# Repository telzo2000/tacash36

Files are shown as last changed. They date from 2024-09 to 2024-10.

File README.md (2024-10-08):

# tacash36

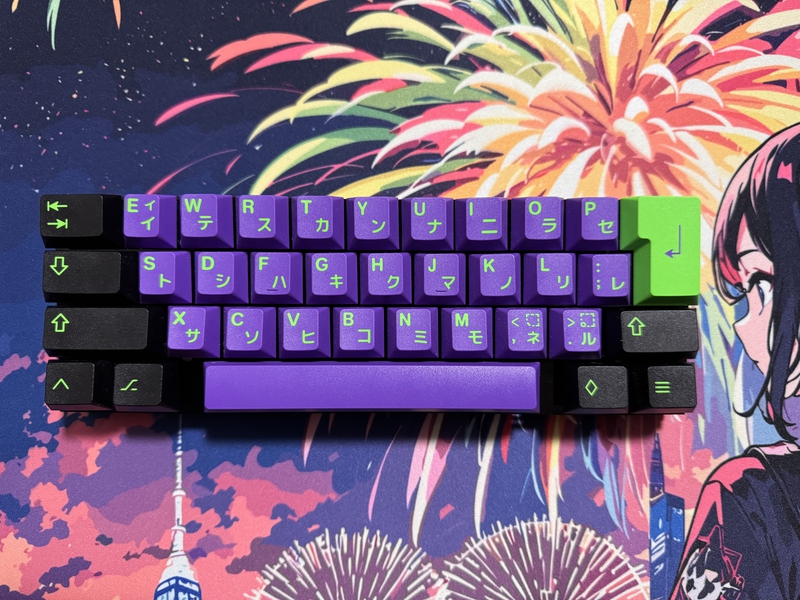
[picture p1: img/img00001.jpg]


## What is tacash36?

tacash36 is small keyboard.
<br>
tacash36 has 36keys.
<br>

This layout has this image.
<br>

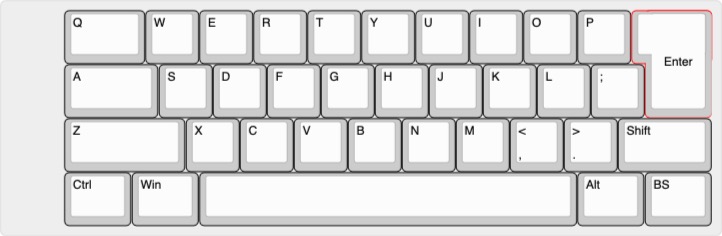
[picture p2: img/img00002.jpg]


This keyboard use Pro micro or BLE Micro Pro, run qmk_firmware.
<br>
With this keyboard, you can edit your favorite keymap using vial.

<br>

## firmware

https://github.com/telzo2000/tacash36/tree/main/firmware

## Build guide

https://github.com/telzo2000/tacash36/blob/main/buildguide_for_tacash36.md

## Parts list

| No. | Patrs | Quantity | remarks | Suppliers | Cost |
|--|--|--|--|--|--|
|番号|名前|数|備考|調達先|参考価格（送料込）|<br>
|1|PCB|1|36key|[elecrow](https://www.elecrow.com)<br>[JLCPCB](https://jlcpcb.com)<br>[ALLPCB](https://www.allpcb.com)|５枚で20〜30ドル|<br>
|2|BLE Micro Pro|1|MCU Board|[遊舎工房](https://shop.yushakobo.jp/products/ble-micro-pro?variant=37665571340449)|4950円|
|3|Swith socket<br>スイッチソケット|36|cherry MX互換|[遊舎工房](https://yushakobo.jp)<br>[Talp Keyboard](https://talpkeyboard.net)<br>[Daily Craft Keyboard](https://shop.dailycraft.jp)等|10個で165円程度|
|4|Diode<br>ダイオード|36|リードタイプでもSMDでも可|[遊舎工房](https://yushakobo.jp)<br>[Talp Keyboard](https://talpkeyboard.net)<br>[Daily Craft Keyboard](https://shop.dailycraft.jp)等|100個で220円程度から|
|5a|Switch plate|1|FR-4|[elecrow](https://www.elecrow.com)<br>[JLCPCB](https://jlcpcb.com)<br>[ALLPCB](https://www.allpcb.com)|５枚で20〜30ドル|
|5b|Switch plate|1|3D Print|||
|5c|Switch plate|1|Acrylic|[elecrow](https://www.elecrow.com/acrylic-cutting.html)|5枚で９ドル程度（送料込み）|
|6|Bottom case|1|3D Print||
|7|Screw<br>ネジ|8|M2 6mm|DIY shop|10本200円程度|
|8|Spacer<br>スペーサー|4|M2 6mm|DIY shop|10本400円程度|
|9|Stabilizer<br>スタビライザー|3|2Ux2,7Ux1|[遊舎工房](https://yushakobo.jp)<br>[Talp Keyboard](https://talpkeyboard.net)|セットで2000円程度|
|10|Conthrou<br>コンスルー|2|3.5mm|[遊舎工房](https://yushakobo.jp)<br>[Talp Keyboard](https://talpkeyboard.net)|１個400円程度|
|11|Keyswitch<br>キースイッチ|36|お好みで|[遊舎工房](https://yushakobo.jp)<br>[Talp Keyboard](https://talpkeyboard.net)<br>[Daily Craft Keyboard](https://shop.dailycraft.jp)|１個100程度|
|12|Keycap<br>キーキャップ|36|1Ux25、1.25Ux4、1.5Ux1、1.75Ux2、2.25Ux1、7Ux1|[遊舎工房](https://yushakobo.jp)<br>[Talp Keyboard](https://talpkeyboard.net)<br>[Daily Craft Keyboard](https://shop.dailycraft.jp)||
|13|ボタン電池ホルダー|1|1632|[アリエク](https://ja.aliexpress.com/item/32744211091.html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)<br>|100個で900円ほど|
|14|水平スライドスイッチ|1||[遊舎工房](https://shop.yushakobo.jp/products/5624?_pos=1&_sid=f65b70e3c&_ss=r)|110円|
|15|チップ積層セラミックコンデンサー |1|100μF6.3V F 3216|[秋月電子](https://akizukidenshi.com/catalog/g/g102151/)|10個入り200円|

※13,14,15は[遊舎工房のこれ](https://shop.yushakobo.jp/products/5623)が最適。

<br>
In addition, you will need a USB cable, etc.
<br>
この他に、USBケーブル等が必要です。
<br>

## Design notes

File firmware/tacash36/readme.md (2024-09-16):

# tacash36

tacash36

*A short description of the keyboard/project*

* Keyboard Maintainer: [m.ki](https://github.com/telzo2000)
* Hardware Supported: *The PCBs, controllers supported*
* Hardware Availability: *Links to where you can find this hardware*

Make example for this keyboard (after setting up your build environment):

    make tacash36:default

Flashing example for this keyboard:

    make tacash36:default:flash

See the [build environment setup](https://docs.qmk.fm/#/getting_started_build_tools) and the [make instructions](https://docs.qmk.fm/#/getting_started_make_guide) for more information. Brand new to QMK? Start with our [Complete Newbs Guide](https://docs.qmk.fm/#/newbs).

## Bootloader

Enter the bootloader in 3 ways:

* **Bootmagic reset**: Hold down the key at (0,0) in the matrix (usually the top left key or Escape) and plug in the keyboard
* **Physical reset button**: Briefly press the button on the back of the PCB - some may have pads you must short instead
* **Keycode in layout**: Press the key mapped to `QK_BOOT` if it is available

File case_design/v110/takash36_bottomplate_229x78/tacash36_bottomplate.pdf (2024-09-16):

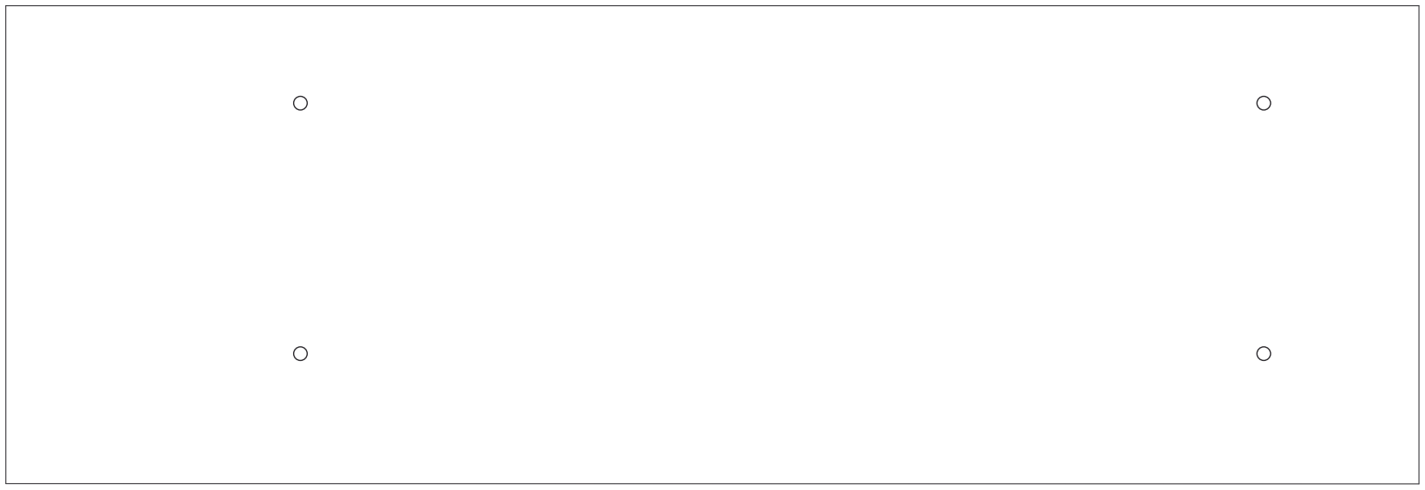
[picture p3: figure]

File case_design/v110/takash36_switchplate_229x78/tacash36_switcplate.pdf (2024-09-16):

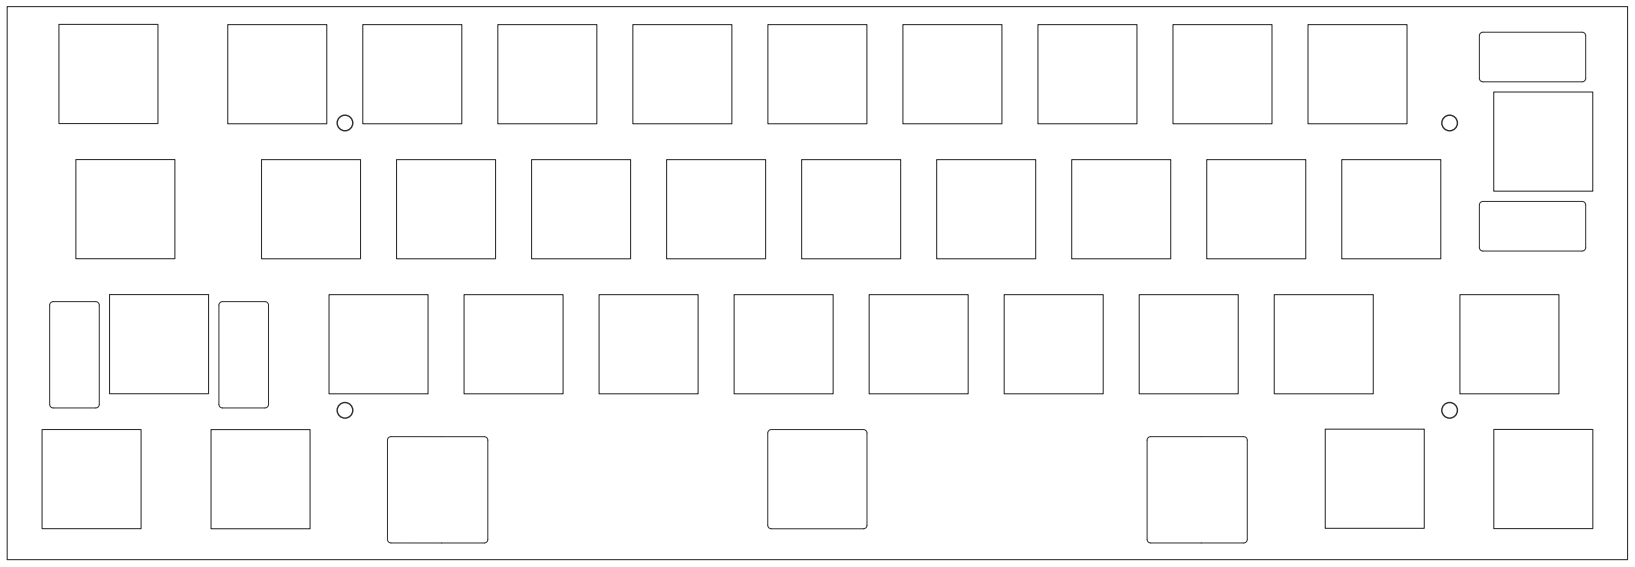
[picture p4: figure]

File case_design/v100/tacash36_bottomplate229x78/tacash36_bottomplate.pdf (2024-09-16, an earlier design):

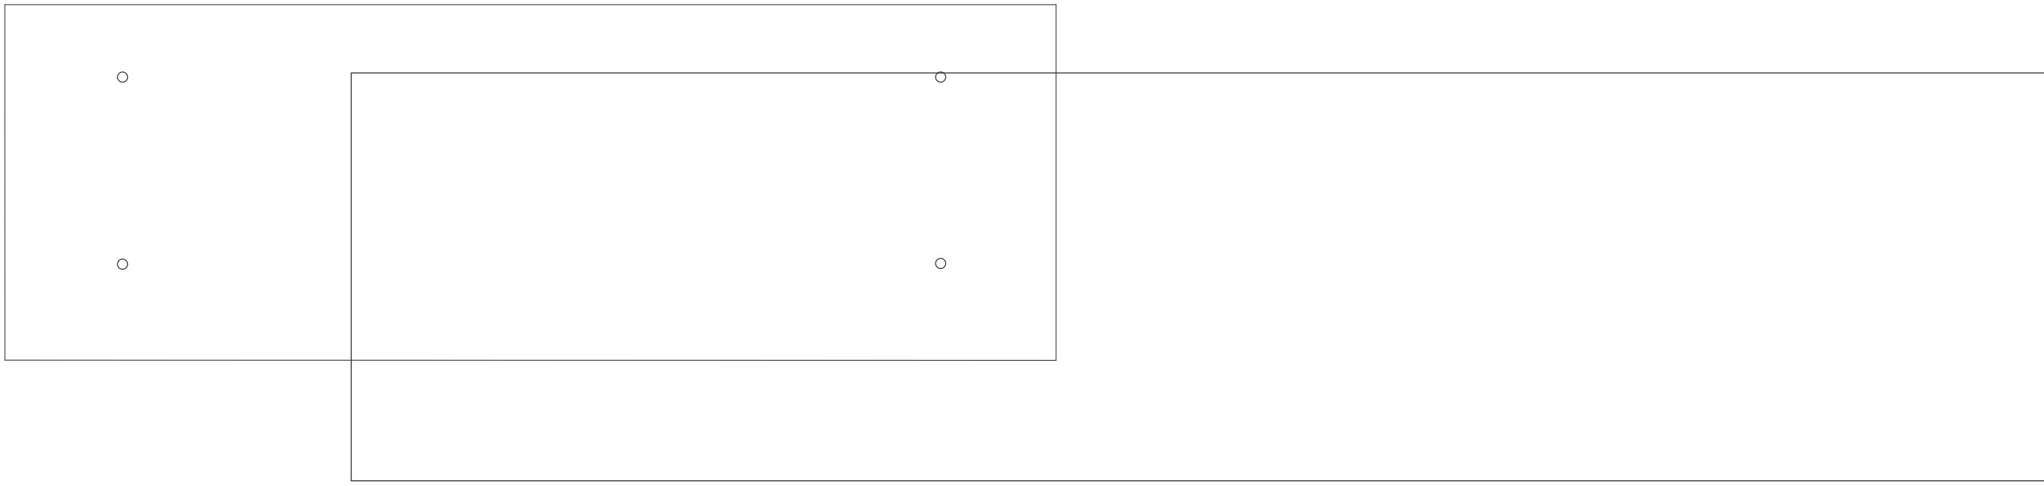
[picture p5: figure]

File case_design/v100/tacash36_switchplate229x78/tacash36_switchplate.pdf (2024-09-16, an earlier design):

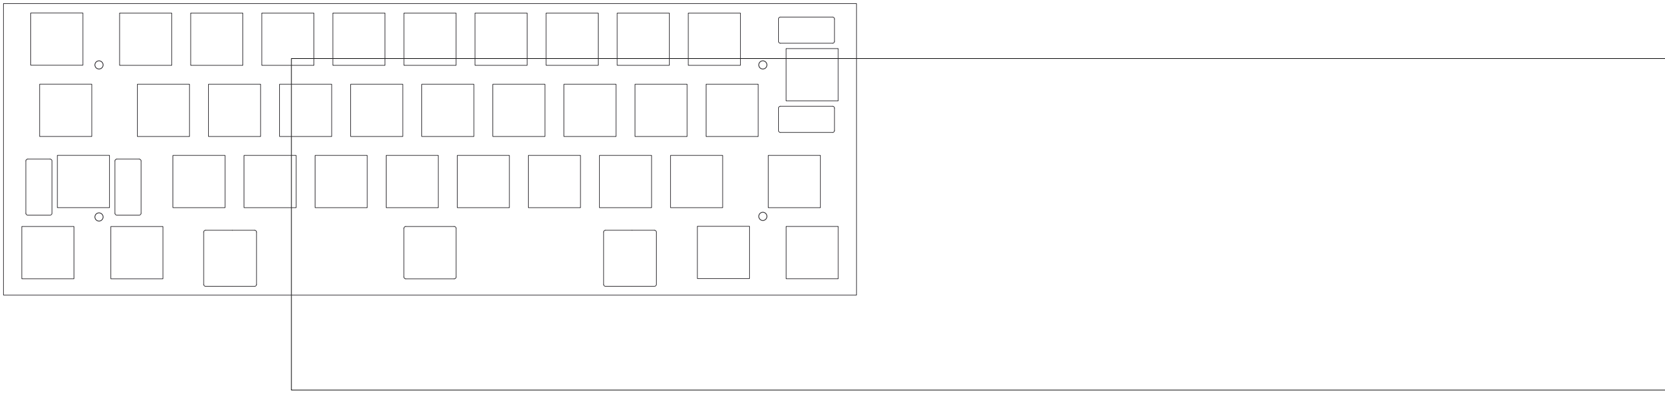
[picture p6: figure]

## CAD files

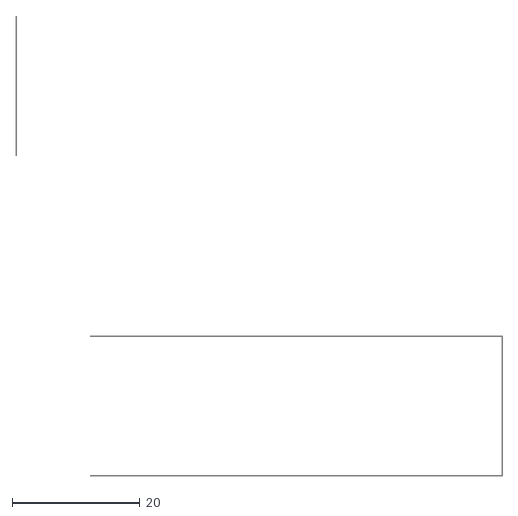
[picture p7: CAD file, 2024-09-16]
case_design/v110/takash36_bottomplate_229x78/tacash36_bottomplate.dxf
76.1 x 72.0

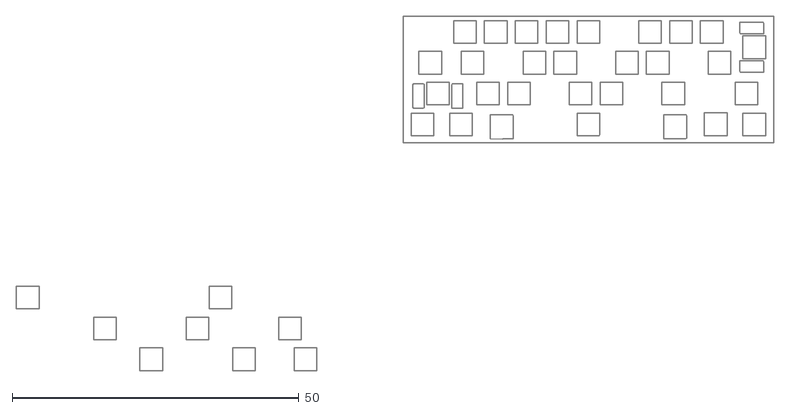
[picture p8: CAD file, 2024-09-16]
case_design/v110/takash36_switchplate_229x78/tacash36_switcplate.dxf
131.9 x 61.7

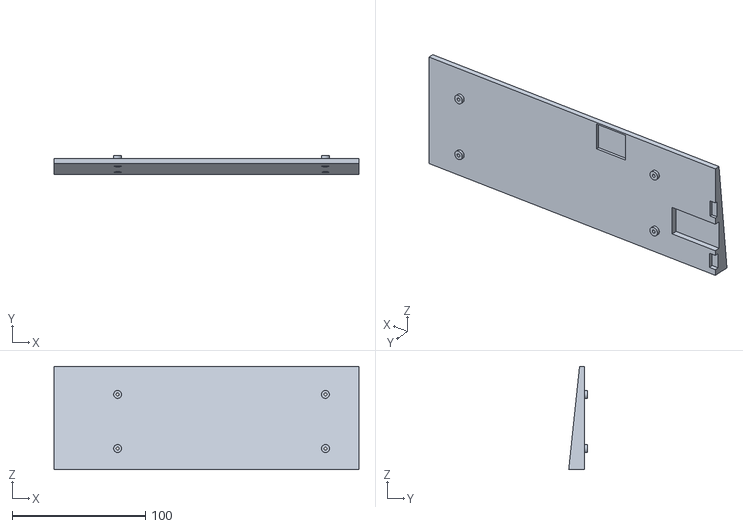
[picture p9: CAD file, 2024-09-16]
case_design/v110_bottomplate_3dprint/tacash36_bottomplate v2.stl
228.6 x 14.0 x 77.5

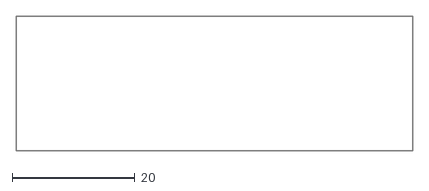
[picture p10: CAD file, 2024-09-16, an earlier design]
case_design/v100/tacash36_bottomplate229x78/tacash36_bottomplate.dxf
64.5 x 21.8

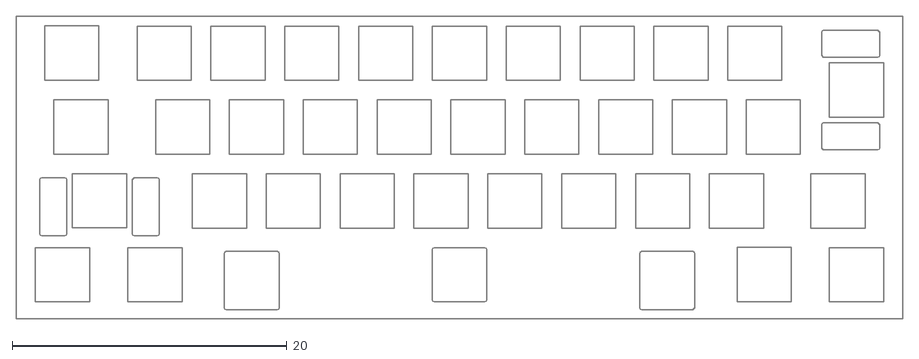
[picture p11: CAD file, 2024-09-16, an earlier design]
case_design/v100/tacash36_switchplate229x78/tacash36_switchplate.dxf
64.5 x 22.0

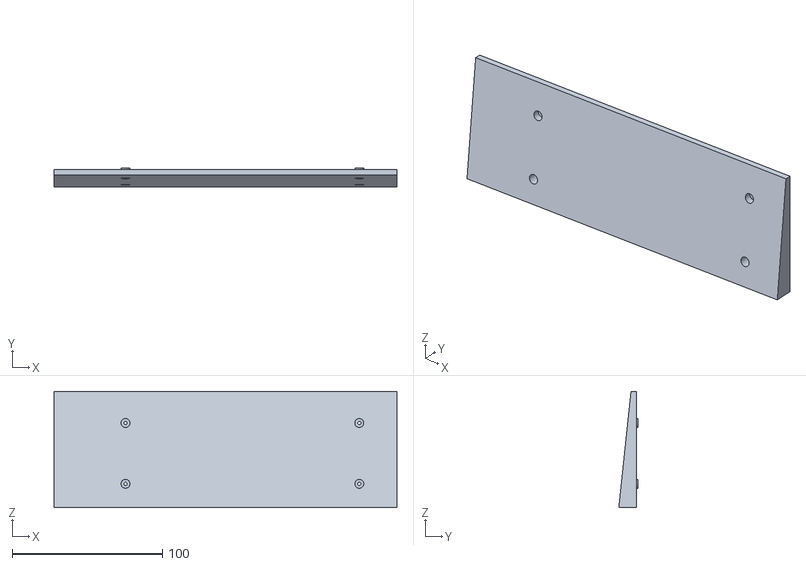
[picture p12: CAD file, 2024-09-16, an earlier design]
case_design/v110_bottomplate_3dprint/tacash36_bottomplate v1.stl
228.6 x 13.0 x 77.5

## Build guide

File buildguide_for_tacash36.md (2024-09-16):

# Build guide

back side of PCB（PCBの裏面）

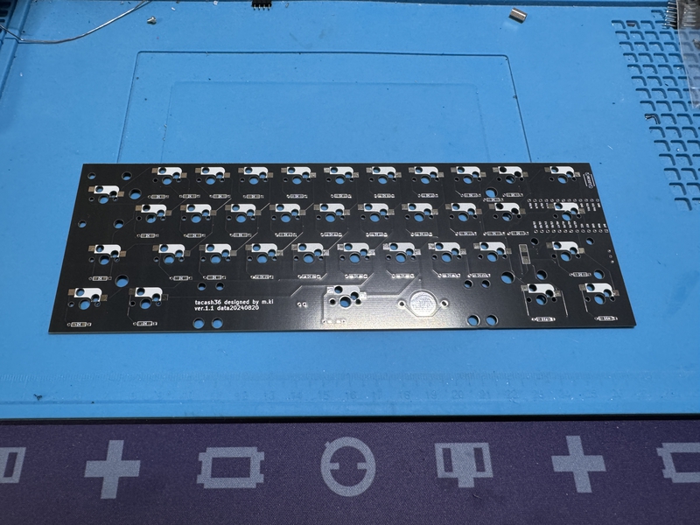
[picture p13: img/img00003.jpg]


## Build 1

### 1 Diode soldering

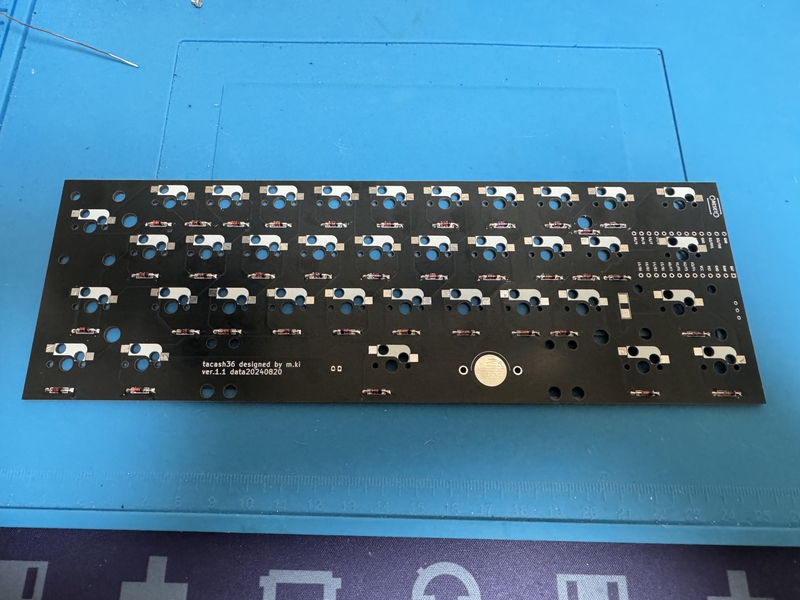
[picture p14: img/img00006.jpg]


Solder the diodes to the back of PCB.
<br>
PCBの裏面にダイオードのハンダ付けをします。
<br>
There are lead type and SMD diodes.
<br>
ダイオードはリードタイプか、SMDがあります。
<br>
Here, we will explain the lead type soldering.
<br>
ここでは、リードタイプのハンダ付けの説明をします。
<br>

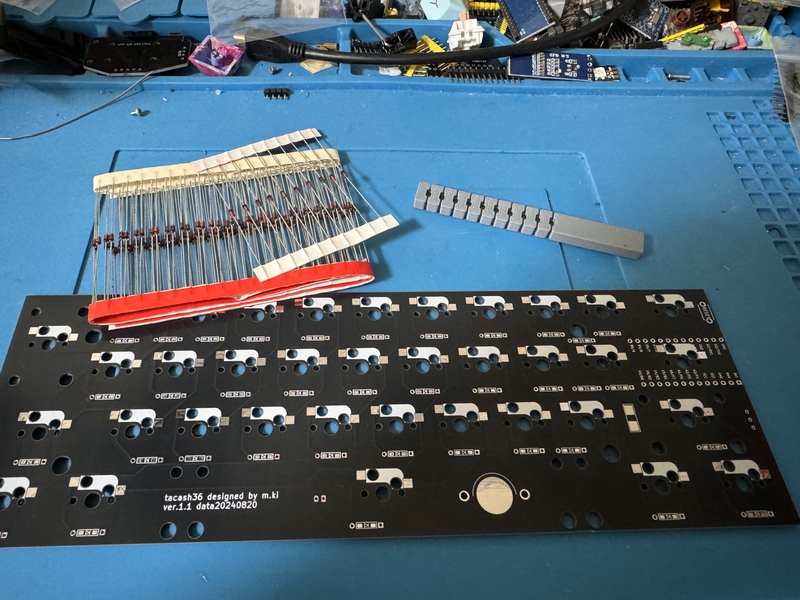
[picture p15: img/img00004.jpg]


Use a lead bender to bend the legs of the diode.
<br>
リードベンダーを使い、ダイオードの足を曲げます。
<br>
Insert the diode into the board.
<br>
ダイオードを基板に挿しこみます。
<br>

Please pay attention to the orientation of the diode.
<br>
ダイオードの向きに注意してください。
<br>

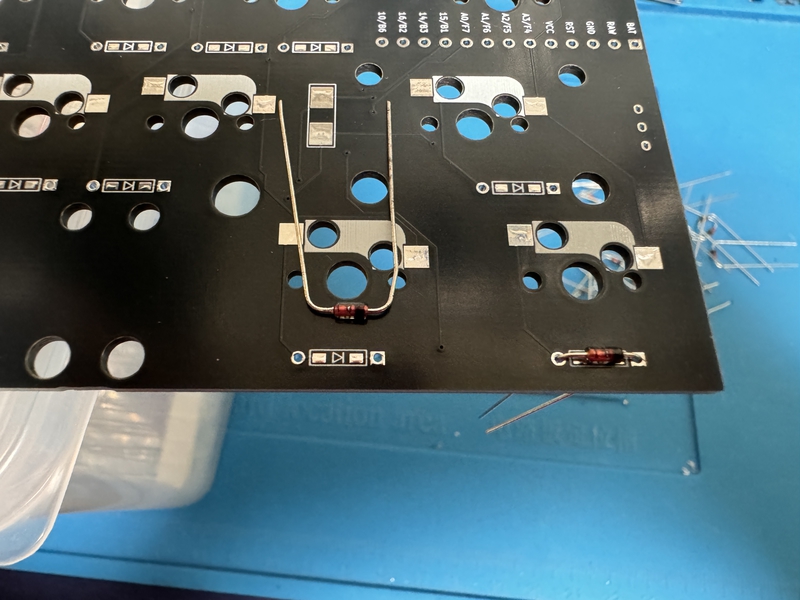
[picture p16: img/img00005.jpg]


Please solder.
<br>
はんだ付けをしてください。
<br>
<br>
Then, cut off the excess lead with nippers.
<br>
その後、余ったリードをニッパーで切り取ってください。

[８倍速　Diodeハンダ付け動画](https://youtu.be/Yaodh2-XxV4)

<br>
<br>

### 2 Switch socket soldering

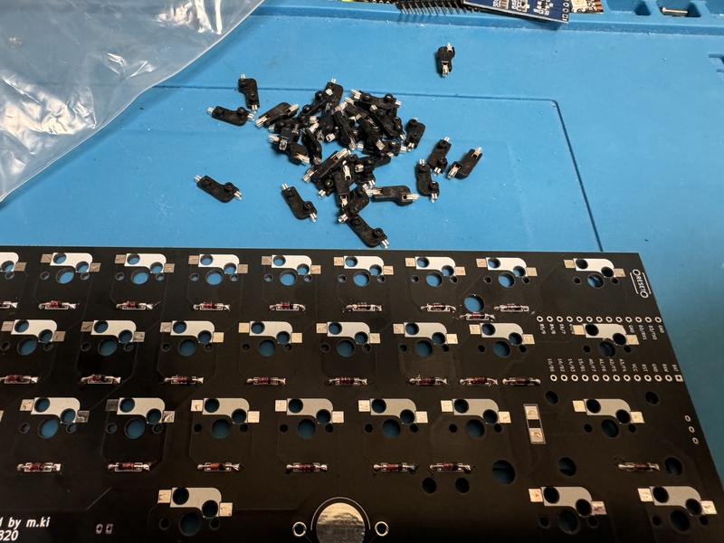
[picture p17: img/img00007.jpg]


Solder the switch sockets on the back side.
<br>
裏面にスイッチソケットのハンダ付けをします。
<br>

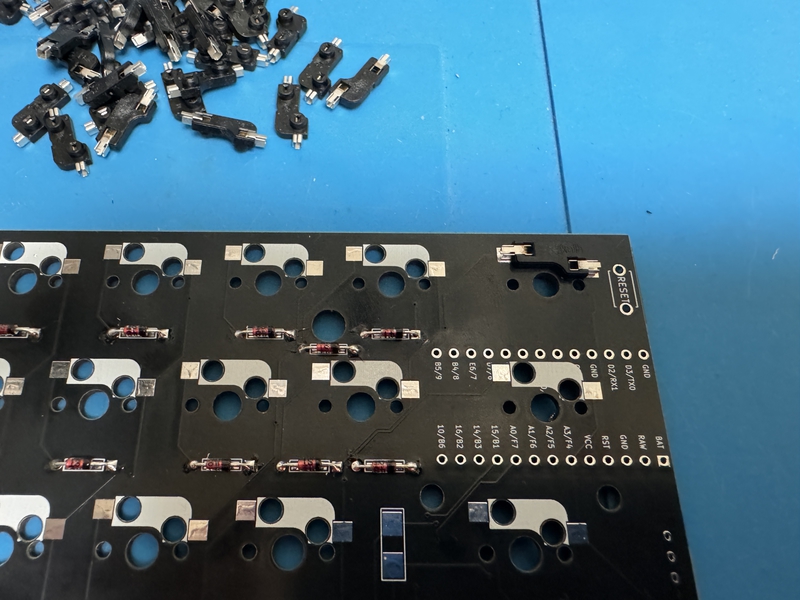
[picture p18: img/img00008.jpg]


[８倍速　Switch socketハンダ付け動画](https://youtu.be/E__mHvmIXQo)

### 3 Reset switch soldering

Insert the reset switch from the back of the PCB and solder the exposed part.
<br>
リセットスイッチをPCBの裏面から差し込んで、表面に出た部分をはんだ付けしてください。
<br>

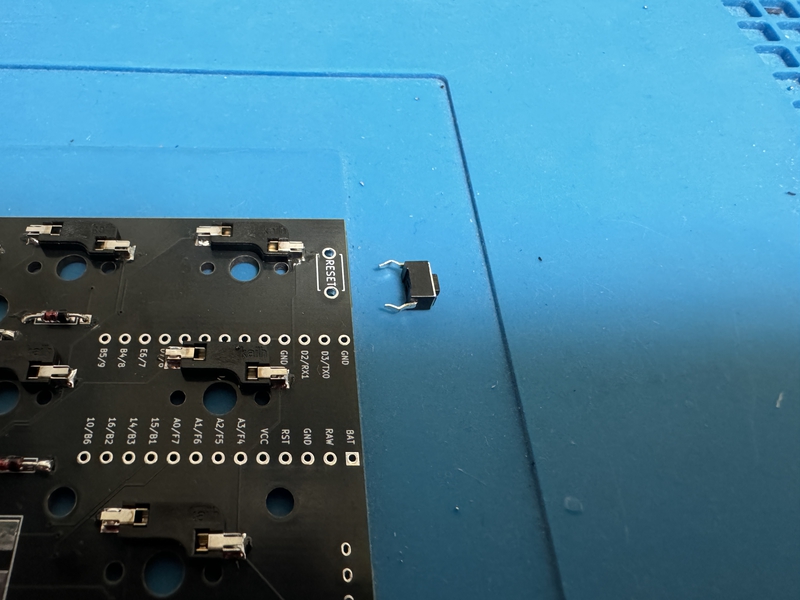
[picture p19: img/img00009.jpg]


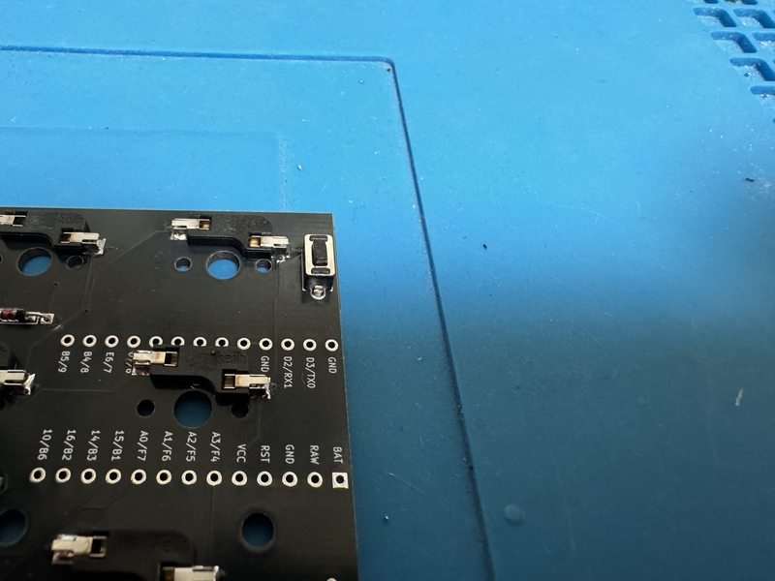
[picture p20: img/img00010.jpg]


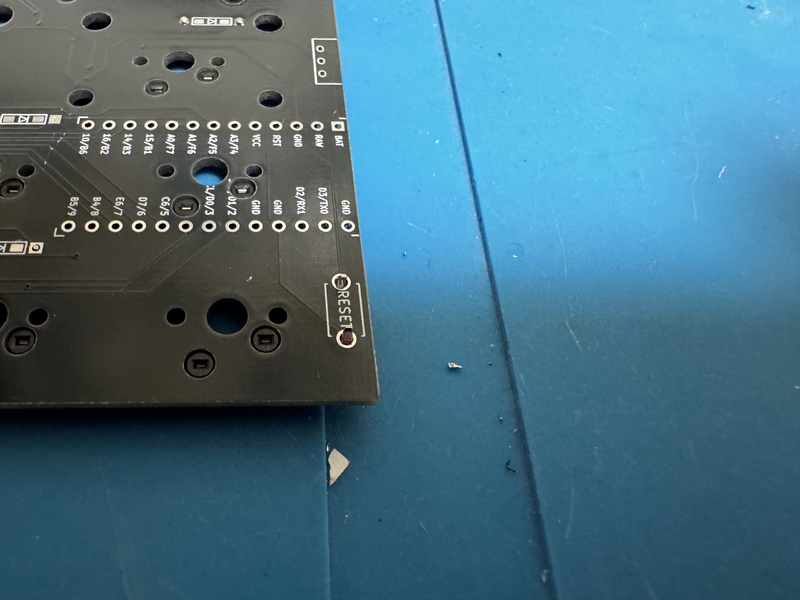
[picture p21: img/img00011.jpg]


### 4 Battery parts soldering(Bluetooth option)

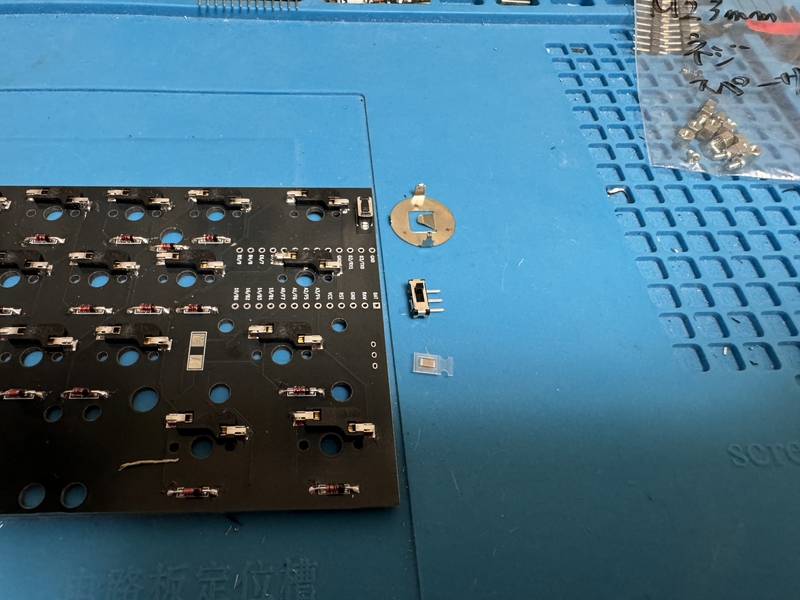
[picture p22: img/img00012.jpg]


Solder the slide switch first.
<br>
最初にスライドスッチをはんだ付けします。
<br>
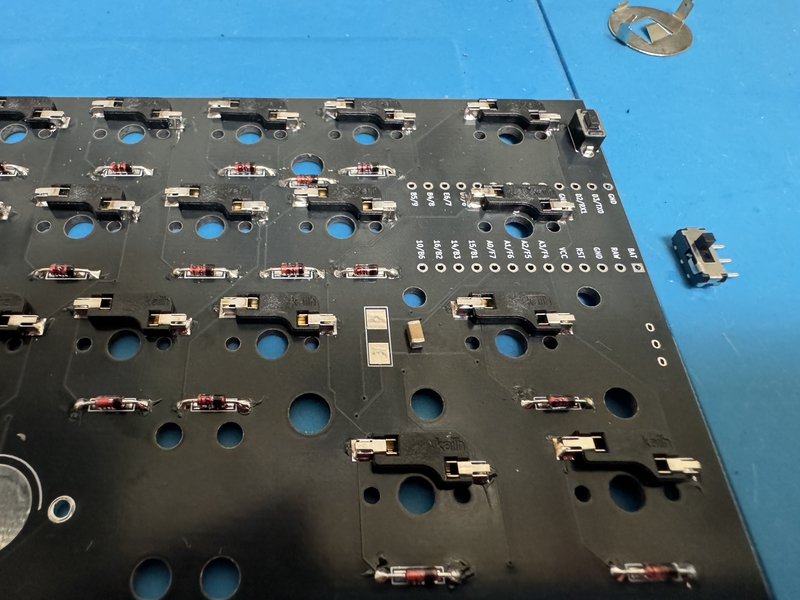
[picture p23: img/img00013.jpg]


Insert the switch from the back of the PCB with the switch knob facing outward.
<br>
スイッチのつまみが外側に向くようにして、PCBの裏面から差し込みます。
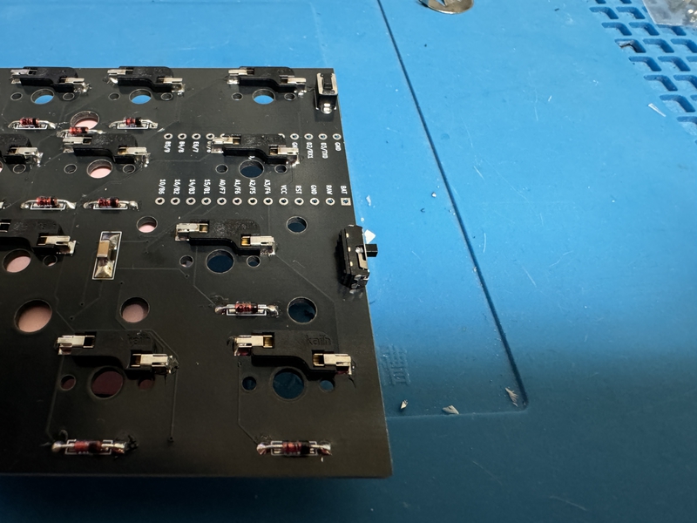
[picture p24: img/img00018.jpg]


After temporarily fixing it with masking tape, etc., solder the exposed part of the PCB.
<br>
マスキングテープなどで仮固定をしてから、PCBの表面に出た部分をはんだ付けします。
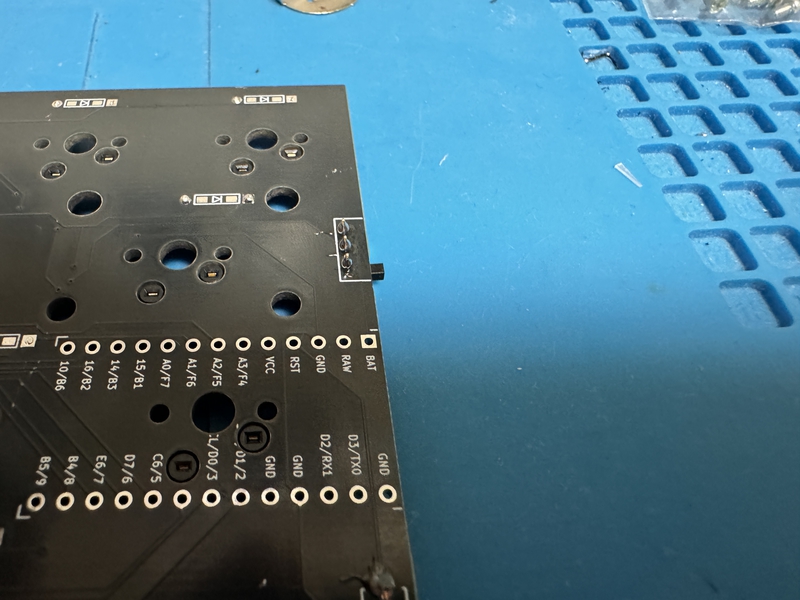
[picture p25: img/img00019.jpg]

<br>
Next, solder the capacitor.
<br>
次に、コンデンサをはんだ付けします。
<br>
<br>
First, apply solder to only one side of the two pads.
<br>
最初に、２つあるパッドの片側だけに、はんだを盛り付けます。
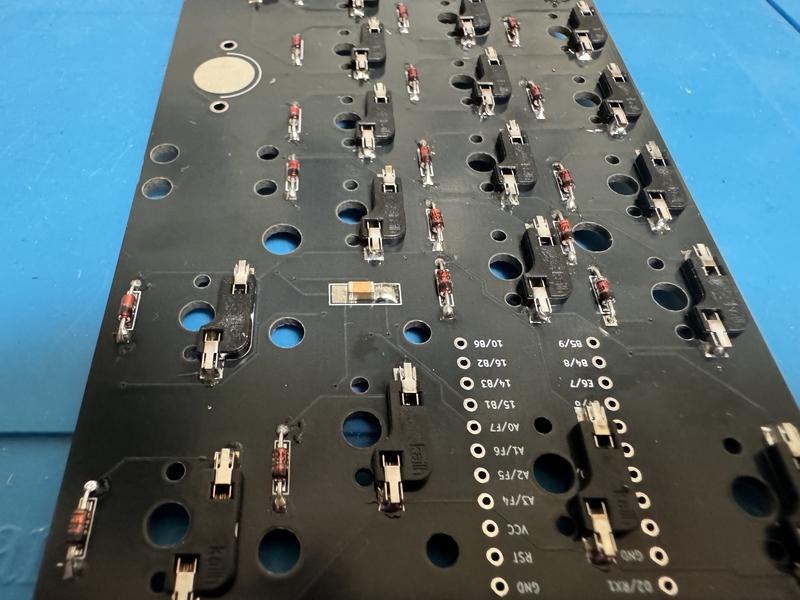
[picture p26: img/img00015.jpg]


Place the capacitor and fix it by melting the solder.
<br>
コンデンサを置き、もったはんだを溶かしながら、固定します。
<br>
Solder the capacitor, applying solder to the remaining pads.
<br>
残りのパッドにはんだを盛りながら、コンデンサをはんだ付けします。
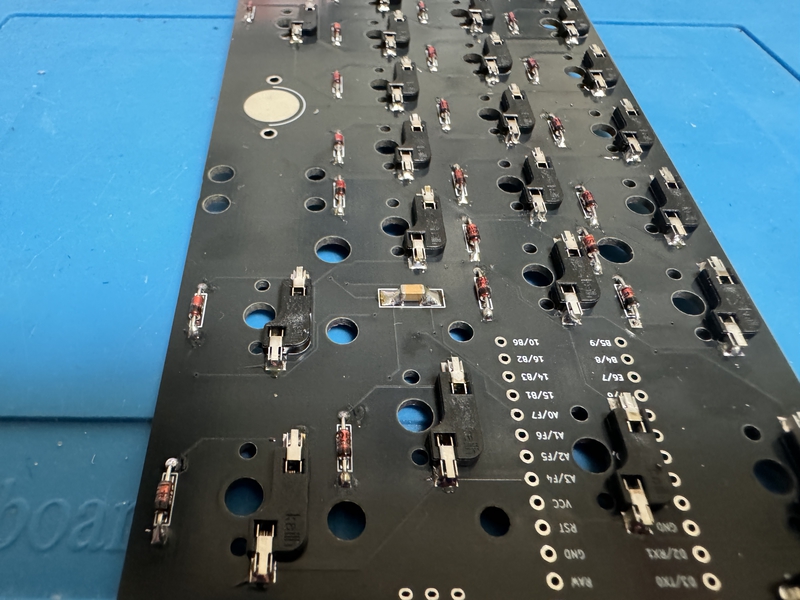
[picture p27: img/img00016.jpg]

Finally, attach the battery holder.
<br>
最後に、電池ホルダを取り付けます。
<br>
Insert it from the back side of the PCB and solder the front side. Using masking tape for temporary fixation will make the work easier.
<br>
PCBの裏面から差し込んで、表面をはんだ付けします。仮固定にマスキングテープを使うと作業が簡単になります。
<br>
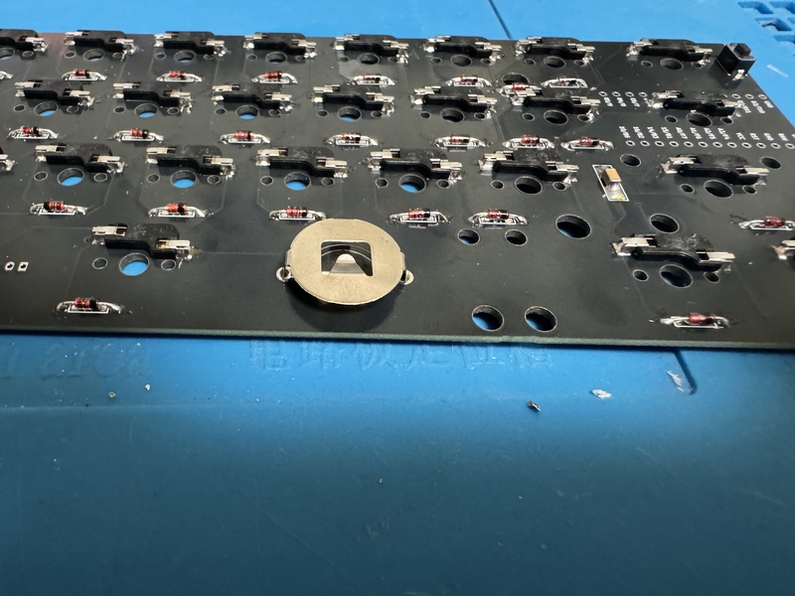
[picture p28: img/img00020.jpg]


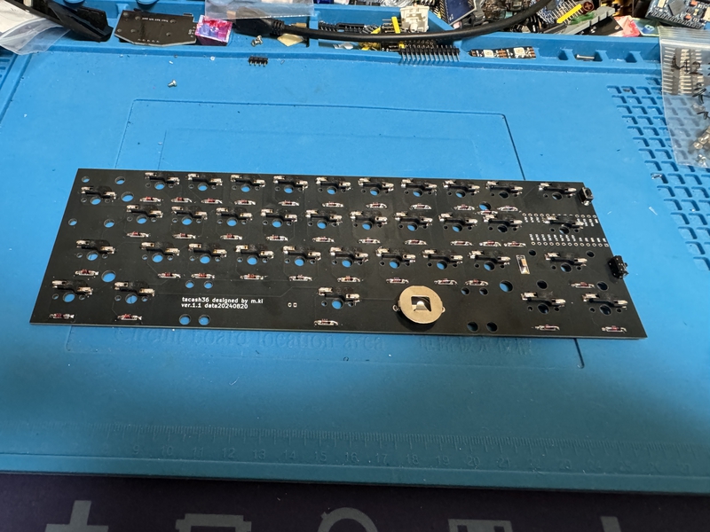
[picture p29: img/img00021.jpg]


### 5a BLE MIcro Pro
Please prepare two con-through (12 pin 2.5mm) instead of the pin header included with BLE Micro Pro.
<br>
ブレマイクロプロ付属のピンヘッダではなく、コンスルー（12ピン 2.5mm）を２つ用意してください。
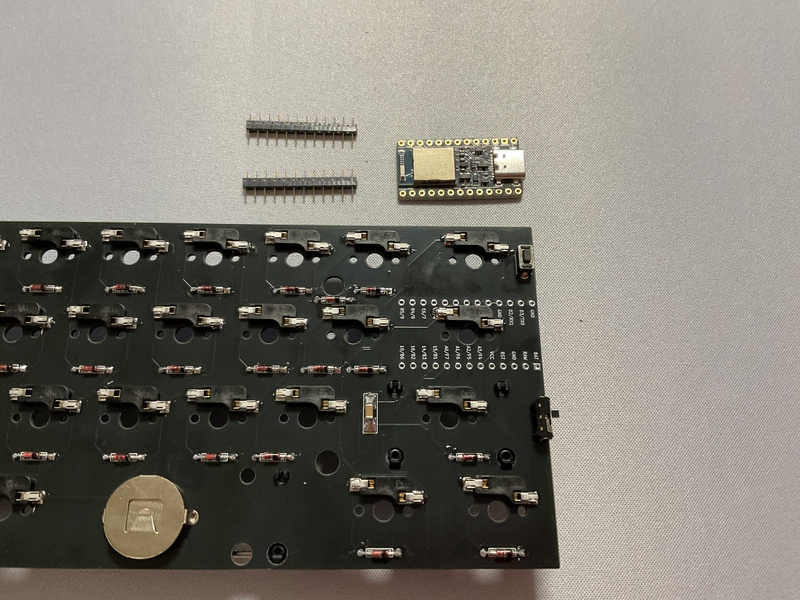
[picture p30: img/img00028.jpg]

There is a small hole in the side of the conthru. Insert it into the PCB, being careful to orient the holes the same way.
<br>
コンスルーの側面に小さい穴が開いています。穴を同じ向きになるよう注意して、PCBに差し込んでください。
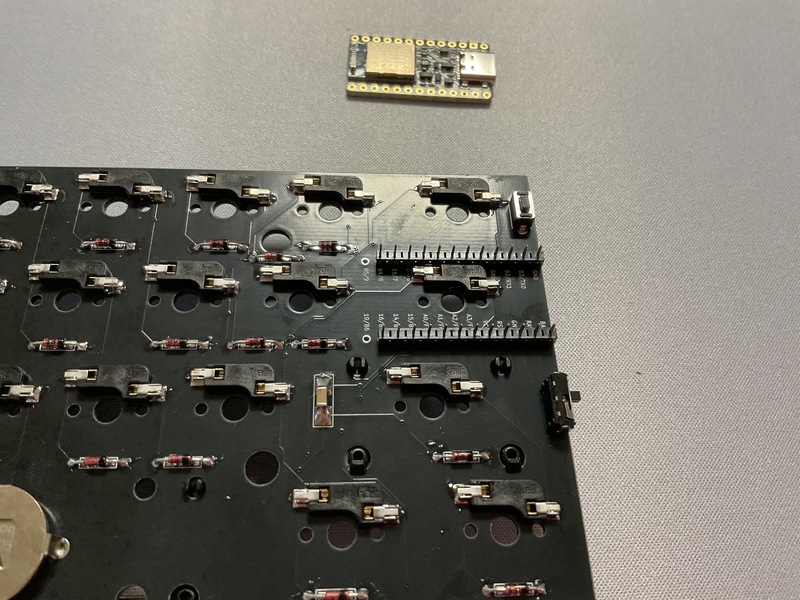
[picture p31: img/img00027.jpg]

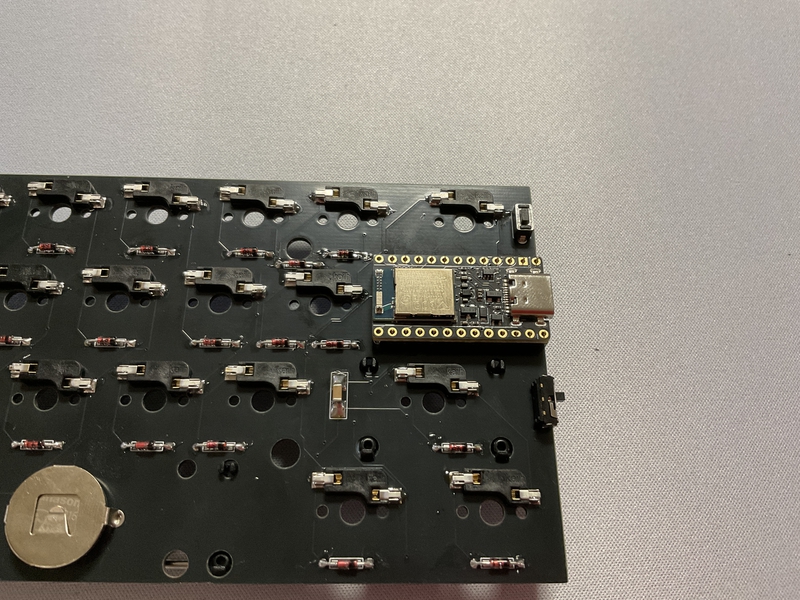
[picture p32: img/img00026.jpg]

Insert it into the con-through so that the part with the  BLE Micro Pro parts is visible. If the  BLE Micro Pro easily comes off from the console, we recommend soldering. However, due to the structure of the bottom plate of the 3D printer, I think it will be difficult to remove, so no soldering is necessary.
<br>
 BLE Micro Proの部品が載っている方が見えるように、コンスルーに差し込んでください。もし、 BLE Micro Proがコンスルーから外れやすいときははんだ付けをお勧めします。ただし、3Dプリンタのボトムプレートの構造上、外れにくいと思うので、はんだ付け不要です。
<br>

### 5b Pro Micro
If you are not interested in wireless connectivity, you can keep the price low by using the pro micro.
<br>
もしあなたが無線接続に興味がないのであれば、pro microを使用することで価格を低くすることができます。
<br><br>
Please prepare two con-through (12 pin 2.5mm) instead of the pin header included with pro micro.
<br>
pro micro付属のピンヘッダではなく、コンスルー（12ピン 2.5mm）を２つ用意してください。
<br>
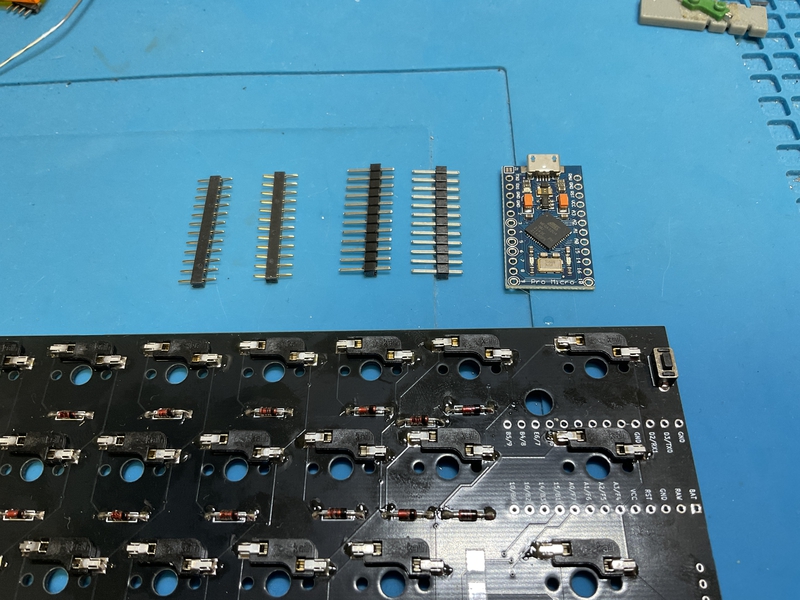
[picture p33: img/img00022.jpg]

There is a small hole in the side of the conthru. Insert it into the PCB, being careful to orient the holes the same way.
<br>
コンスルーの側面に小さい穴が開いています。穴を同じ向きになるよう注意して、PCBに差し込んでください。
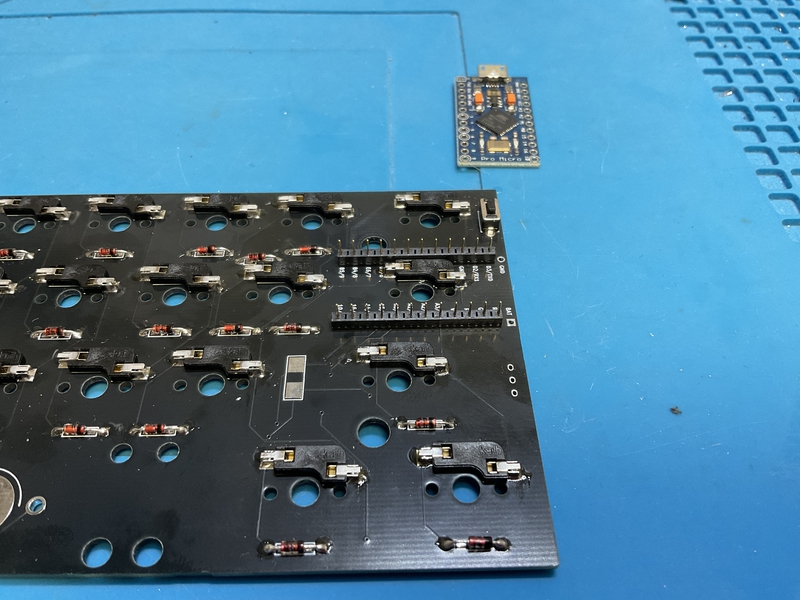
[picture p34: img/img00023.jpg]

Insert it into the con-through so that the part with the pro micro parts is visible. If the pro micro easily comes off from the console, we recommend soldering. However, due to the structure of the bottom plate of the 3D printer, I think it will be difficult to remove, so no soldering is necessary.
<br>
pro microの部品が載っている方が見えるように、コンスルーに差し込んでください。もし、pro microがコンスルーから外れやすいときははんだ付けをお勧めします。ただし、3Dプリンタのボトムプレートの構造上、外れにくいと思うので、はんだ付け不要です。
<br>
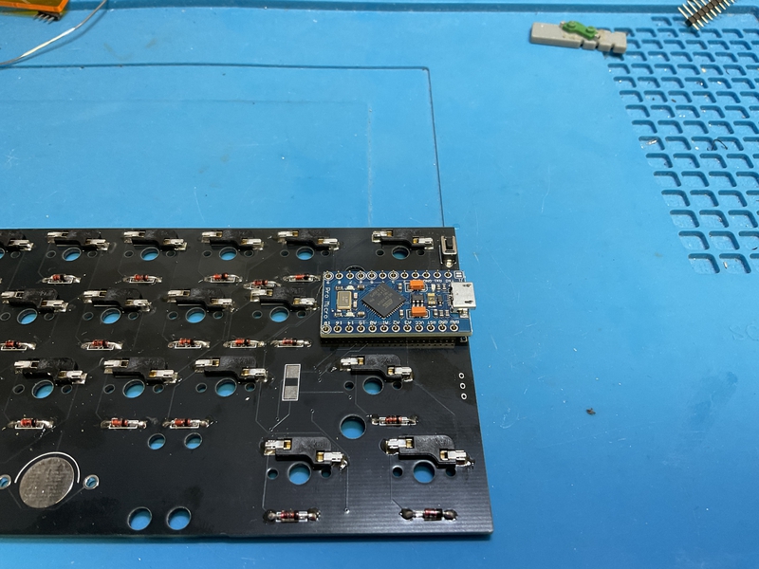
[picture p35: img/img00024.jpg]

Some of them are soldered.
一応はんだ付けしたものもです。
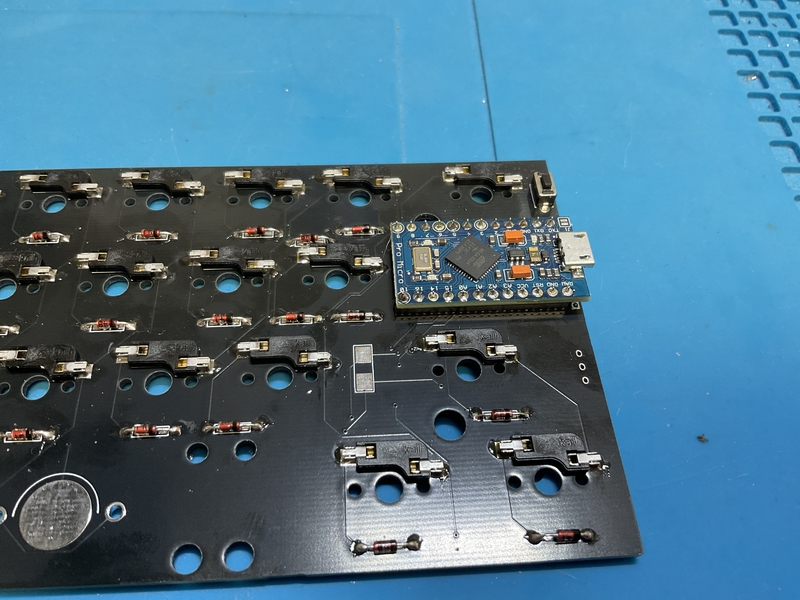
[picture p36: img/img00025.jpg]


### 6a Install firmware （BLE Micro Pro）

Here is an [article](https://sizu.me/m_ki/posts/01s8uea4u7x8) on how to do it.
<br>
ここにやり方の[記事](https://sizu.me/m_ki/posts/01s8uea4u7x8)があります。
<br>

### 6bInstall firmware （pro micro）

There is a hex file [here](https://github.com/telzo2000/tacash36/tree/main/firmware). Please install it using QMK ToolBox.
<br>

[ここ](https://github.com/telzo2000/tacash36/tree/main/firmware)にhexファイルがあります。それを、QMK ToolBoxを使って、インストールしてください。

[QMK ToolBox](https://qmk.fm/toolbox)

キーマップ編集サイト
[Vial](https://get.vial.today/)

### 7 Fix the stabilizer

Attach the stabilizer to the surface of the PCB.
<br>
PCBの表面にスタビライザーを装着してください。
<br>

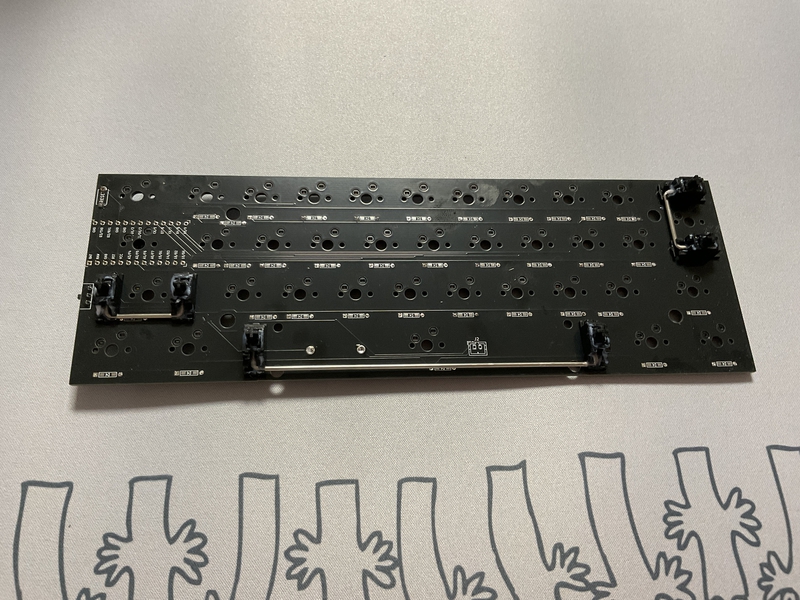
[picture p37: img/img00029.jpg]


The stabilizer will operate smoothly if it is greased.
<br>
スタビライザーはグリスをしておくと、滑らかに稼働します。
<br>
<br>

### 8 Fix the switch plate(Acrylic) with screws

Insert the acrylic switch plate, the M2 spacer (3mm), and the M2 screw (8mm) in that order to secure it.
<br>
アクリルのスイッチプレート、M2スペーサー（6mm）の順でM2ネジ（8mm）の順で差し込んで固定します。
<br><br>
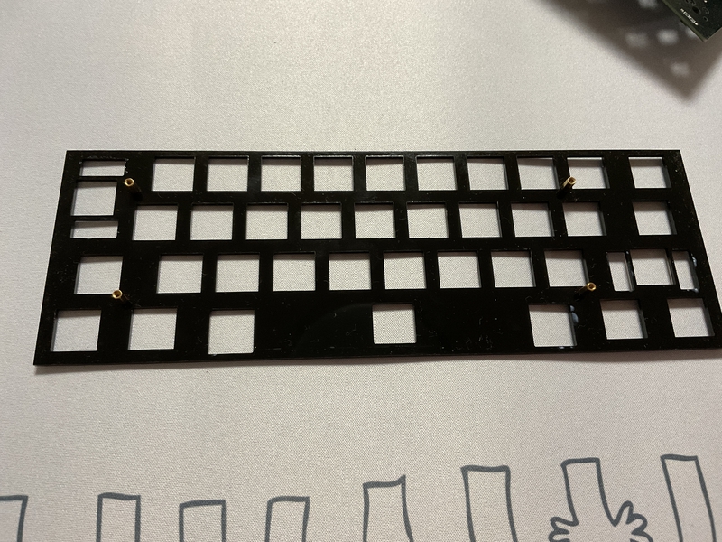
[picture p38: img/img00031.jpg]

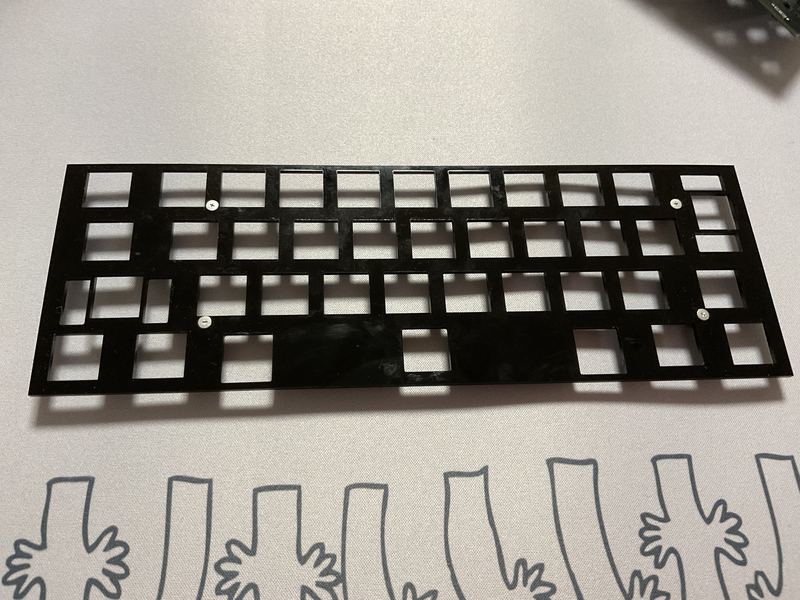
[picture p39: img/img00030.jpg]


### 9 Insert the key switch

Insert the key switch from the switch plate side.
<br>
スイッチプレート側からキースイッチを差し込んでいきます。
<br>
<br>
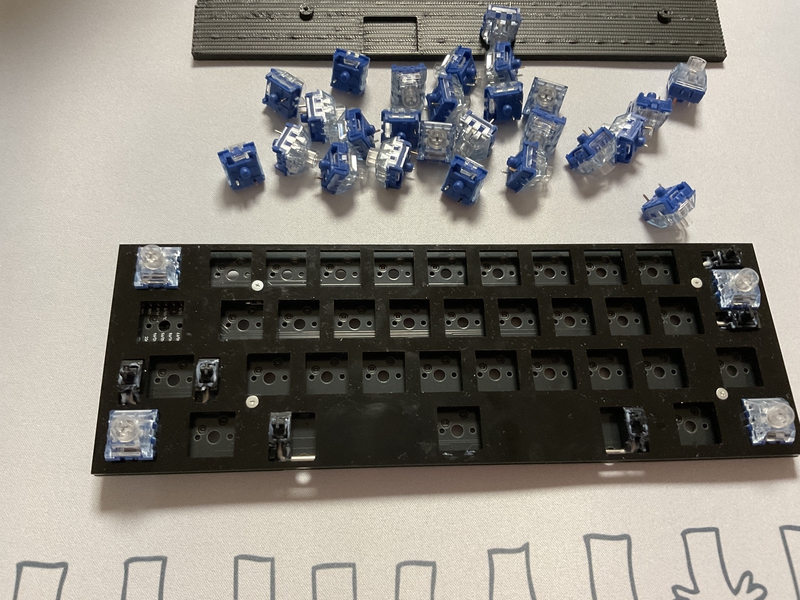
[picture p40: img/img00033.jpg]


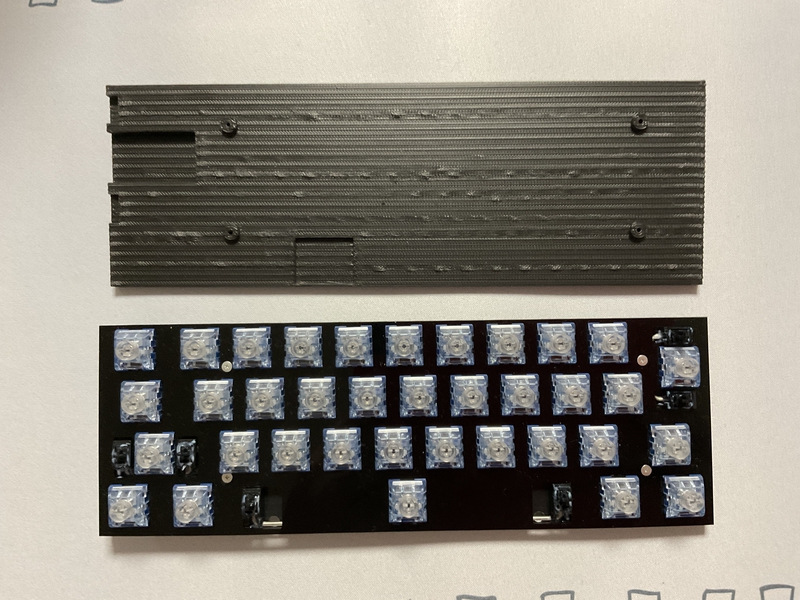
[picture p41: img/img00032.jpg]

<br>

### 10 Fix the bottom plate with screws

Secure the bottom plate with four M2 screws (6mm).
<br>
ボトムプレートをM2ネジ（6mm）４本で固定します。
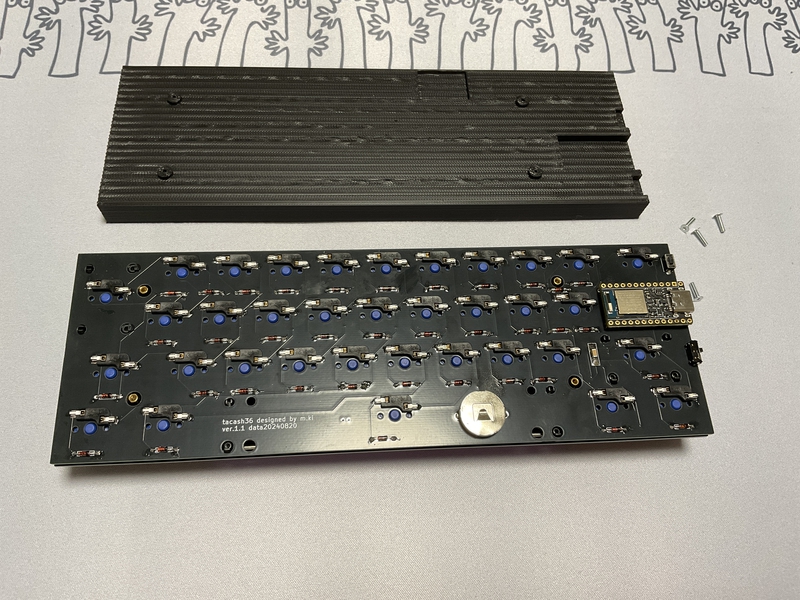
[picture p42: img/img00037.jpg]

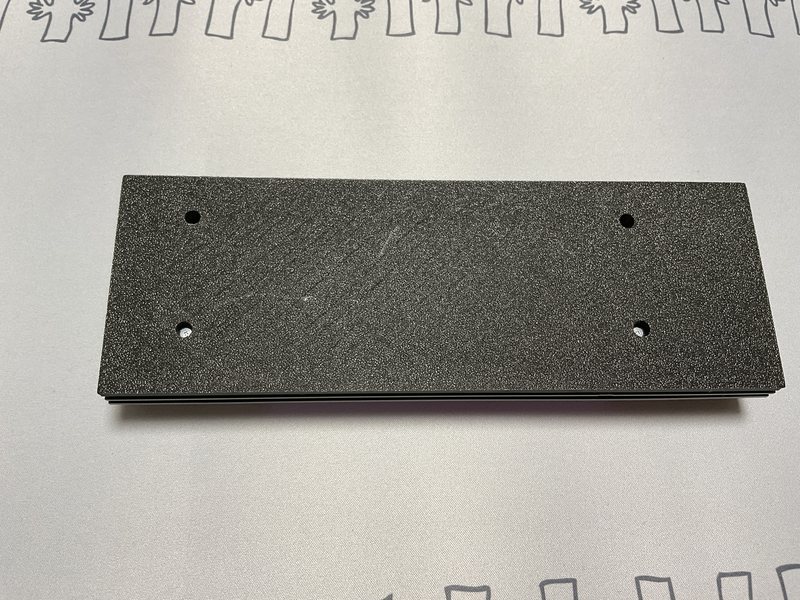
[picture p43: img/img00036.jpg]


### 11 Complete

Attach your favorite keycaps and you're done.
<br>
お気に入りのキーキャップをつけて完成です。
<br>
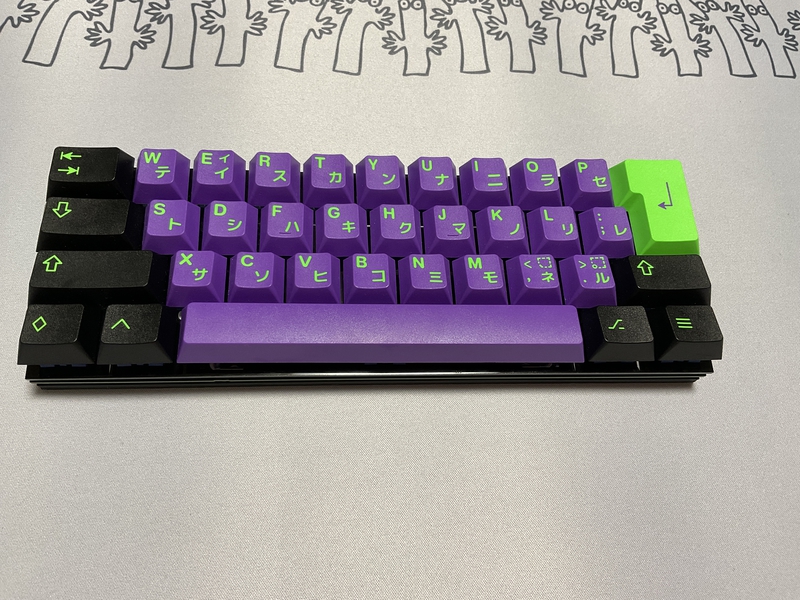
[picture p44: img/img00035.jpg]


<br>
Welcome to the world of the best keyboards.
<br>
最高のキーボードの世界にようこそ。
<br>
